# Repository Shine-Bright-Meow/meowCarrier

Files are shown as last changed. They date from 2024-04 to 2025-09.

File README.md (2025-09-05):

# meowCarrier
PCB, case, and accessories as a do-it-yourself solution for SlimeVR Full Body Trackers. Ordering and assembly instructions can be found in the README file.

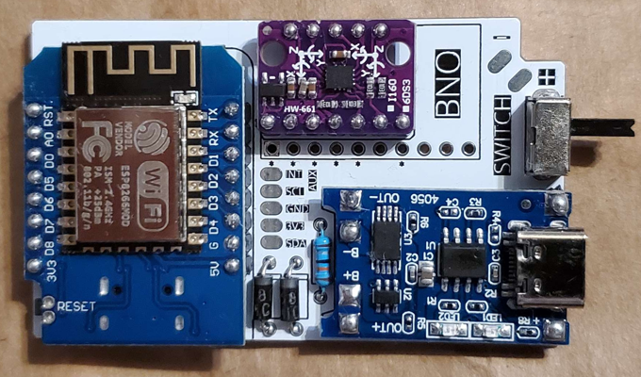
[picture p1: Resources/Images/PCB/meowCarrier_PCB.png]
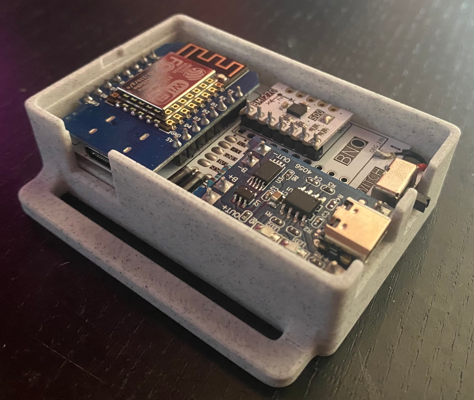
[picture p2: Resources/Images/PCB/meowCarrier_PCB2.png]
<div align="center" valight="center"><br></div>

## Purchasing Guide
### Recommended Components (PCB)
Choose either LSM6DSV / ICM-45686 (Performance) or LSM6DSR (Value) from the list below; not all three.

| Component | Variant | Link |
| --- | --- | --- |
| WeMos D1 Mini | Micro or Type-C (not V4.0.0) | <https://www.aliexpress.us/item/2251832465432818.html><br><https://hz.aliexpress.com/item/3256804158044498.html><br><https://www.aliexpress.us/item/3256805831695231.html> |
| TP4056 | 18650 Micro or Type-C | <https://www.aliexpress.us/item/2251832290307200.html><br><https://www.aliexpress.us/item/2251832397113841.html> |
| ICM-45686 | N/A | <https://shop.slimevr.dev/products/slimevr-mumo-breakout-module-v1-icm-45686-qmc6309> |
| LSM6DSR | N/A | <https://moffshop.deyta.de/products/lsm6dsr> |
| LSM6DSV | N/A | <https://moffshop.deyta.de/products/lsm6dsv-module> |
| SK12D07/SK12D07VG Switch | High 3mm | <https://www.aliexpress.us/item/3256804216279588.html> |
| 1/4W Metal Film Resistor | 180**K** | <https://www.aliexpress.us/item/3256803737288214.html> |
| Schottky Rectifier Diode | 1N5817 | <https://www.aliexpress.us/item/2255800018624086.html> |
| Header Pins | 2.54mm Pitch / Male | <https://www.aliexpress.us/item/3256805804439042.html> |
| Lithium Polymer Ion Battery | 503759 or 523450 without connector | <https://www.aliexpress.us/item/3256805125875396.html><br><https://www.aliexpress.us/item/3256806672906854.html><br><https://www.aliexpress.us/item/3256806672783913.html> |

> [!IMPORTANT]
> Purchase 30% more boards (WeMos D1 Mini and TP4056) than what is needed. There is the possibility that components are dead on arrival or get damaged during assembly or soldering.

> [!NOTE]
> One order of Resistors, Diodes, Header Pins, and Switches is enough for the entire project.

> [!NOTE]
> The SlimeVR DIY Community recommends buying boards from the following sellers on AliExpress: Win Win, Aitexm, or Tenstar Robot.

> [!NOTE]
> Type-C Ports are more durable. As for charging, USB-C to USB-C Power Delivery doesn't work. Use USB-A to USB-C cables to charge trackers.

> [!IMPORTANT]
> When purchasing components, some have multiple variants on the same product page, like Diodes and Resistor. Be sure to select the correct one.

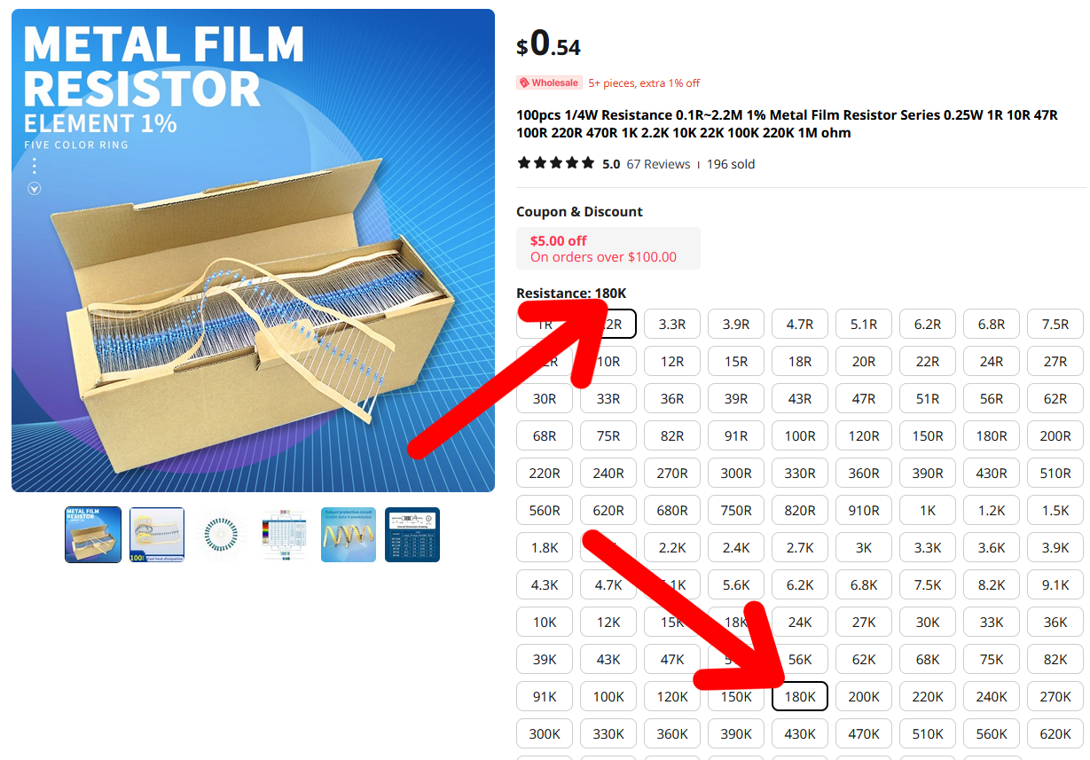
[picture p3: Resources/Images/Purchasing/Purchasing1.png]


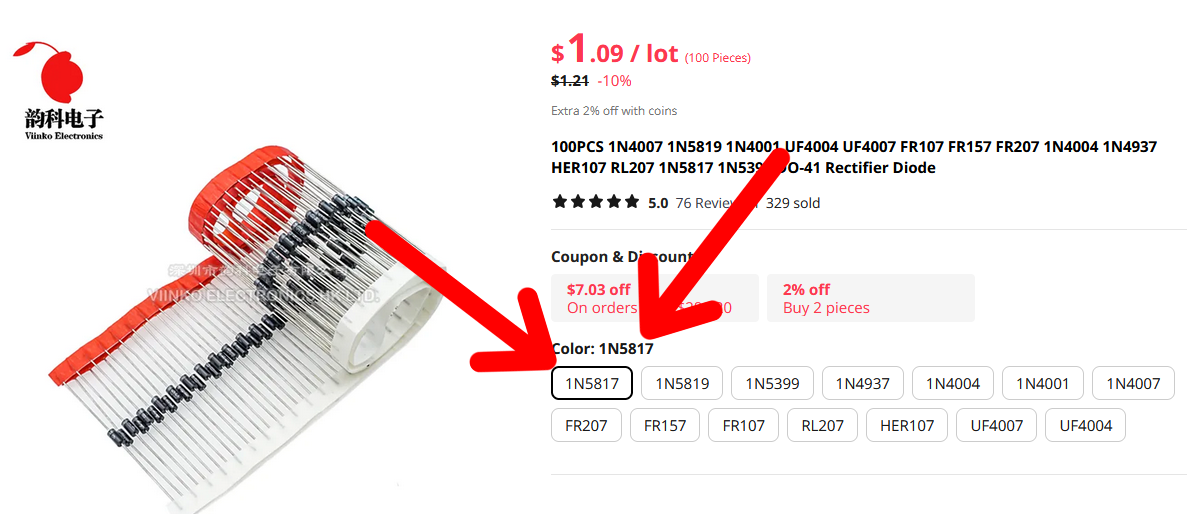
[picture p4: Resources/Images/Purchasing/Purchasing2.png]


> [!TIP]
> In your AliExpress Cart, you can verify that you selected the correct variant of the component here.

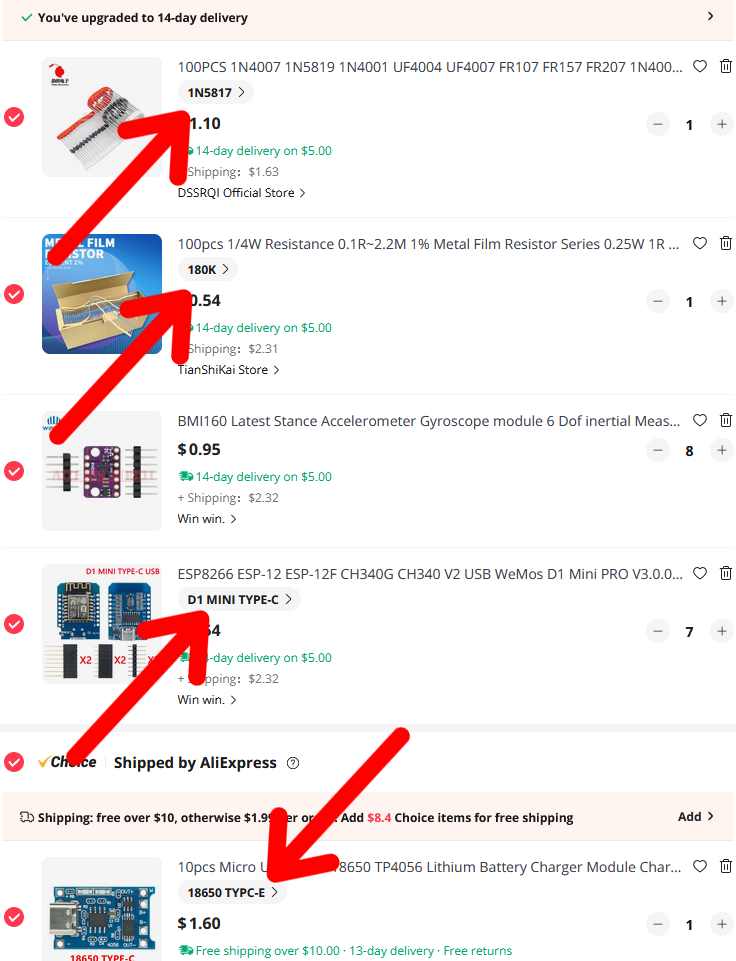
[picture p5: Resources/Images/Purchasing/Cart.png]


### Optional Components (PCB)
| Component | Variant | Link |
| --- | --- | --- |
| Sheathed Wire Cable | 28AWG & 4Cores | <https://www.aliexpress.us/item/2255800384086289.html> |

### Recommended Consumables and Tools
| Component | Variant | Link |
| --- | --- | --- |
| Soldering Iron | Any with BC2 Tip | <https://www.aliexpress.us/item/3256805553022893.html> |
| Solder Sucker| SS-02 or SS-02 Clone | <https://www.aliexpress.us/item/3256805437410900.html> |
| Desoldering Iron| Choose your electrical outlet | <https://www.aliexpress.us/item/3256804929123151.html> |
| Rosin Flux | Liquid or Gel Type | N/A |

> [!NOTE]
> You will have a much better soldering experience with better tools. These are my recommended (but still on a budget) Soldering Iron and Solder Sucker if you don't have these tools or better already. They will work much better than those Amazon $10–20 soldering kits and irons.

> [!NOTE]
> The soldering iron listed requires a USB Type-C Power Delivery charging block of 60W or higher.

### Recommended Components (Case)
| Component | Variant | Link |
| --- | --- | --- |
| Trilancer Elastic Cinch Straps | See note below | <https://www.amazon.com/dp/B099RNRT7Z> |
| GoPro Chest Mount Harness | See note below | <https://www.aliexpress.us/item/3256805774922789.html> |
| GoPro Chest Mount Harness (Chesty) | Option B (with the thumb screw) | <https://www.aliexpress.us/item/2251832640172299.html> |

> [!NOTE]
> 12 inches work for ankles. 18 inches for thinner thighs and 24 inches for thicker thighs. Chest (if not using the GoPro Chest Harness) and Hips can be done by doubling up on 18- or 24-inch straps. Choose what you need for your body and how many trackers you are planning to make. A 3-size combo and either an 18- or 24-inch package would be a start.

> [!NOTE]
> There are two types of GoPro Chest Mount Harness. If the intended user of the trackers has a larger chest, it is recommended to get the "Chesty" harness for comfort. One that clips in, and the other one is fastened by a bolt. Be sure to print the correct GoPro Adapter case.

### Ordering PCBs from JLCPCB
1. Download the Gerber file from [here](https://github.com/Shine-Bright-Meow/meowCarrier/raw/main/PCB/PCB_meowCarrier.zip).
2. Go to [JLCPCB](https://jlcpcb.com).
3. Click on "Add Gerber File" and upload the zip Gerber file.

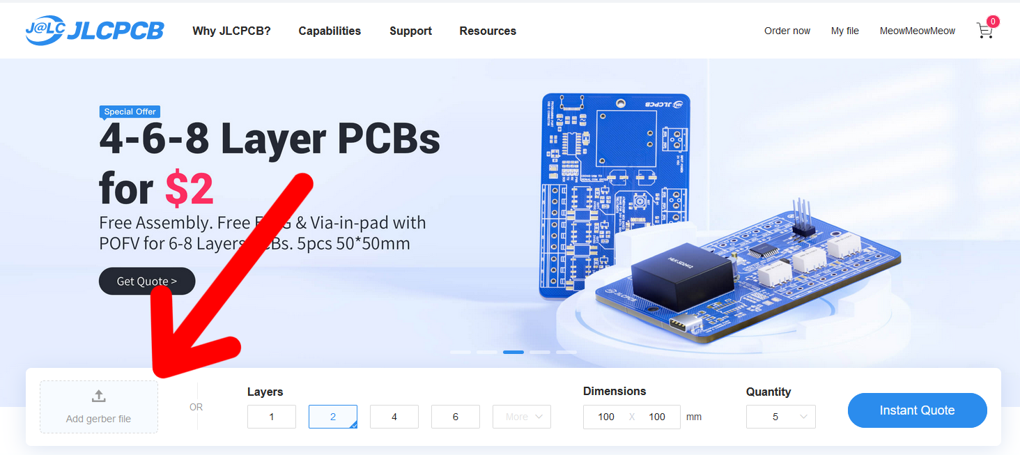
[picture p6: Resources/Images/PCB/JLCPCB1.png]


4. Select the PCB Qty and PCB Color of your choice. Select 0.8mm (recommended) or 1.0mm for PCB Thickness and select "Specify a location" for Remove Order Number.

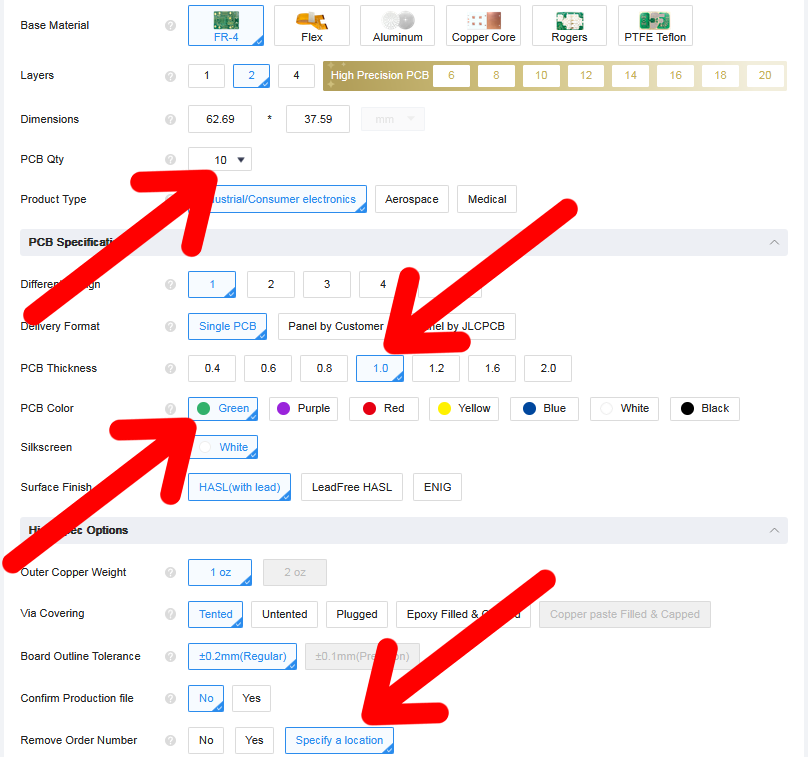
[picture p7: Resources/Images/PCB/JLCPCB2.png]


> [!NOTE]
> Using 0.8mm will give you more assembly tolerance and the tracker will be slightly lighter.

> [!NOTE]
> JLCPCB usually manufactures Green colored PCB the quickest. Other colors have additional days added.

> [!NOTE]
> For Remove Order Number, when "Specify a Location" is selected, JLCPCB will print the order number at where the text **JLCJLCJLCJLC** is located. In this case, at the bottom of the TP4056 module footprint.
5. Click to View Cart.

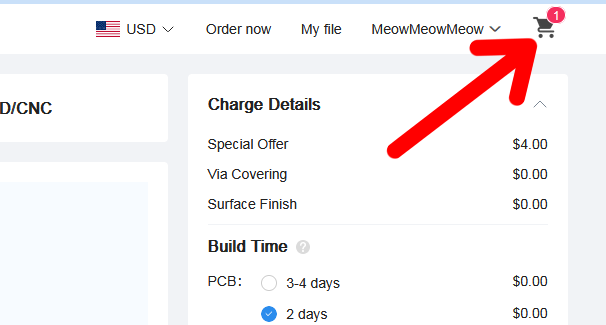
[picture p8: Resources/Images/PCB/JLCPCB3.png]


6. Click Secure Checkout.

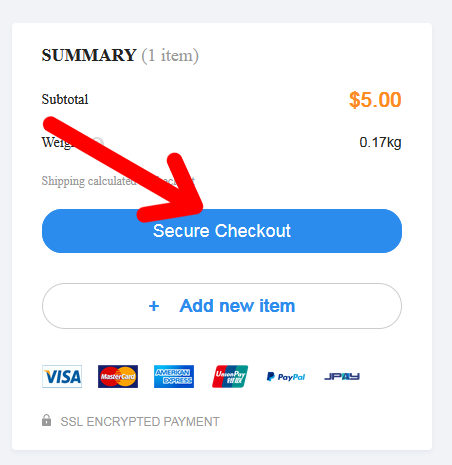
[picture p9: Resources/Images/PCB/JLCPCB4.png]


7. In the Shipping section, there are cheaper options not chosen by default.

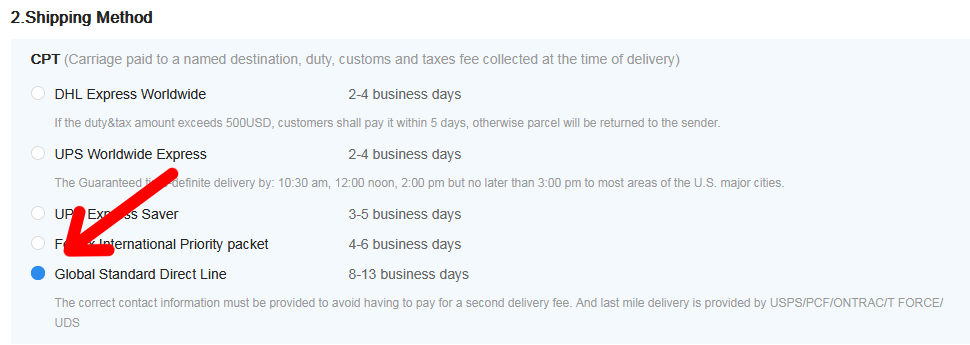
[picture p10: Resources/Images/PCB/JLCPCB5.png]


## Soldering/Assembly Guide

### Written Guide

> [!WARNING]
> Please work in a well-ventilated area. It is recommended to use a fume extractor if working indoors. If you do not have one, use a fan to blow fumes or smoke away from your face.

> [!WARNING]
> It is recommended to use eye production. Especially when splitting header pins apart with a cutter and when trimming down header pins and ends of resistors and diodes.

> [!WARNING]
> If working with leaded solder, be sure to wash your hands when you are done, including under your fingernails. Wipe down and vacuum the floors and surfaces of your workspace and anything you may have cross-contaminated.

> [!TIP]
> Using external flux (preferably Rosin) will allow the solder to flow automatically flow into the correct area.

> [!TIP]
> A wooden clothespin can be used to hold the boards together while soldering.

##### Diodes

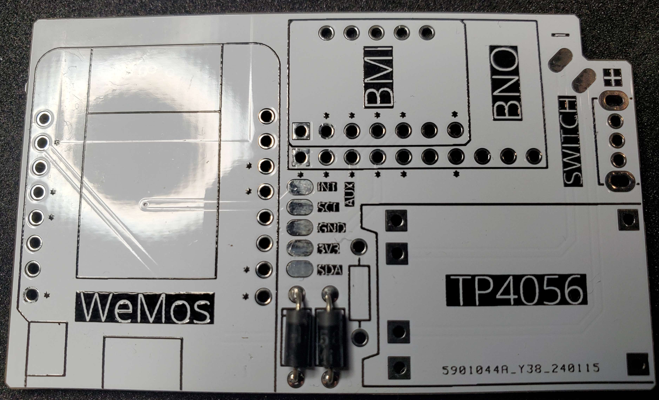
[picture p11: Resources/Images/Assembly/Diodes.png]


> [!NOTE]
> Make sure the diode is facing the correct direction and has the correct values.

1. Verify that the diodes are 1N5817. You can find the text in the body.

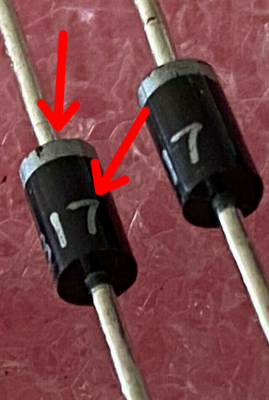
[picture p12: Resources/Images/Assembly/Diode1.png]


2. Place the diode's striped (grey or silver) on the narrow stripe indicated on the silkscreen.

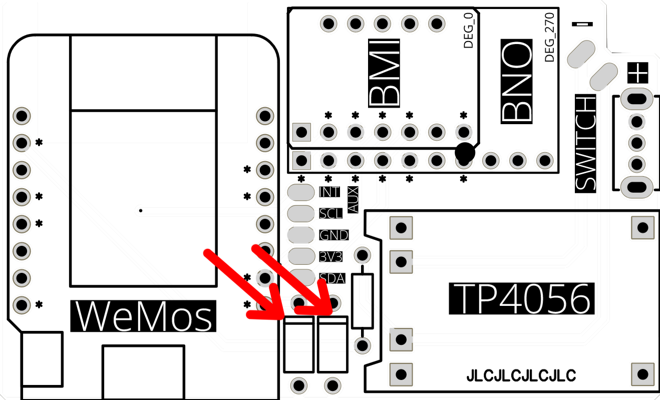
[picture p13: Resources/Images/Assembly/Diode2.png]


3. Bend the ends in 90 degrees so they are shaped like a staple and place them into the through-hole.
4. Pull the excess on the back until the diode is flush with the PCB.
5. Solder ends from the back.
6. Repeat for the other diode.
7. Trim the excess length of the pins using a flush cutter. Use your wire cutter if you don't have a flush cutter, and cut as close to the PCB as you can.

##### Resistor

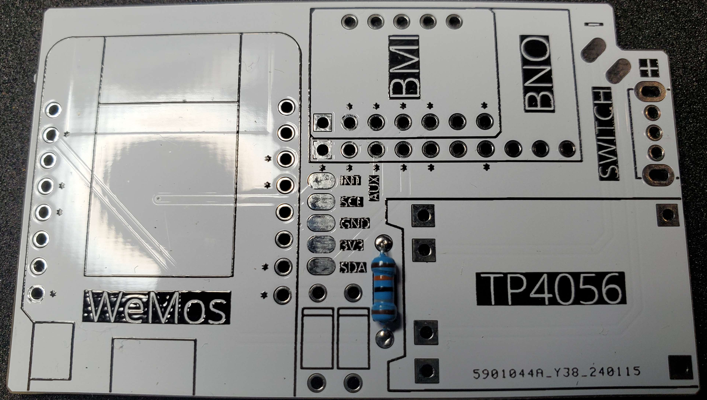
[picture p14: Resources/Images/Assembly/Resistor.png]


> [!NOTE]
> Make sure the resistor has the correct value.

1. Verify the resistor is 180K. The first four colors should go in this order:
- Brown
- Grey
- Black
- Orange

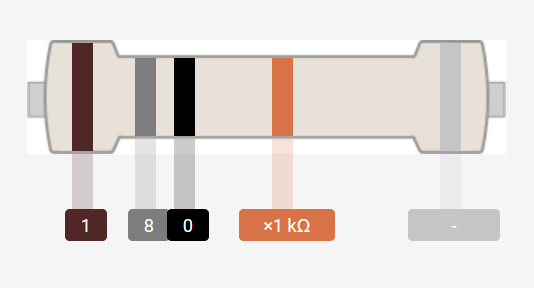
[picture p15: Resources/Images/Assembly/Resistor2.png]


2. Bend the ends in 90 degrees so they are shaped like a staple and place them into the through-hole. Resistors are not polarized, so the direction does not matter.
3. Pull the excess on the back until the resistor is flush with the PCB.
4. Trim the excess length of the pins using a flush cutter. Use your wire cutter if you don't have a flush cutter, and cut as close to the PCB as you can.

> [!NOTE]
> Unlike Diodes, Resistors can go into the PCB in any direction.

#### Charging Board (TP4056)

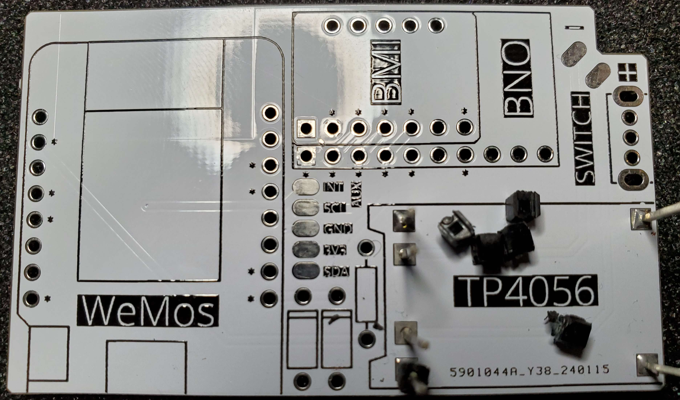
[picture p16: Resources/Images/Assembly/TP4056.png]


1. Break the header into individual pins.
2. Place individual pins into the through-holes.
3. Place the TP4056 on top of the header pins to sandwich them in place.
4. If needed, use a clamp, like a wooden clothespin, to hold everything in place.
5. Solder the pins to the back of the PCB.
6. Remove the TP4056 from the PCB and header pins.
7. Using a plier, carefully remove the black plastic spacer from the header pins.
8. Replace the TP4056 back through the Header pins.
9. Solder the header pins and top side of the TP4056.
10. Trim the excess length of pins using a flush cutter on the back side of the PCB and the top side of the TP4056. Use your wire cutter if you don't have a flush cutter, and cut as close to the PCB as you can.

#### IMU (ICM-45686, LSM6DSR, or LSM6DSV)

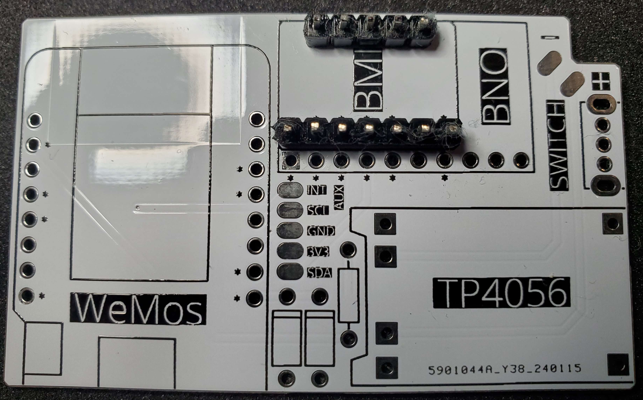
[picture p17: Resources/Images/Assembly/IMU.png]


1. Break a row of header pins with the same amount of through-holes as the IMU breakout board.
2. Place the header pins in the corresponding through-holes of the PCB.
3. Solder the pins to the back of the PCB.
4. Solder the header pins and top side of the IMU.
5. Trim the excess length of pins using a flush cutter on the back side of the PCB and the top side of the IMU. Use your wire cutter if you don't have a flush cutter, and cut as close to the PCB as you can.

#### MCU (WeMos D1 Mini)

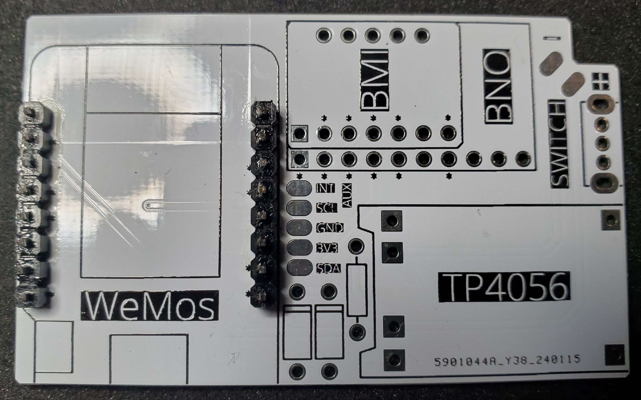
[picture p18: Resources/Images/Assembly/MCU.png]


1. Flash the D1 Mini with WiFi credentials to ensure the board is in working condition first.
2. Place both rows of header pins into the through-holes of the PCB.
3. Place D1 Mini on top of the header pins to sandwich them in place.
4. If needed, use a clamp, like a wooden clothespin, to hold everything in place.
5. Solder the pins to the back of the PCB.
6. Solder the header pins and top side of the D1 Mini.
7. Trim the excess length of pins using a flush cutter on the back side of the PCB and top side of the D1 Mini. Use your wire cutter if you don't have a flush cutter, and cut as close to the PCB as you can.

#### Switch

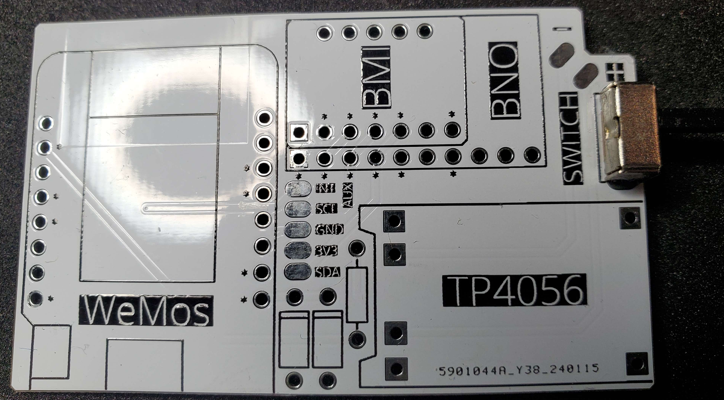
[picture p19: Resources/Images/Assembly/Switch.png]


1. Place the Switch into the through-holes of the PCB.
2. Solder the 3 pins and the 2 supports on the back of the PCB.
3. Trim the excess length of pins and supports using a flush cutter on the back side of the PCB.

#### Extension Cable/Wire

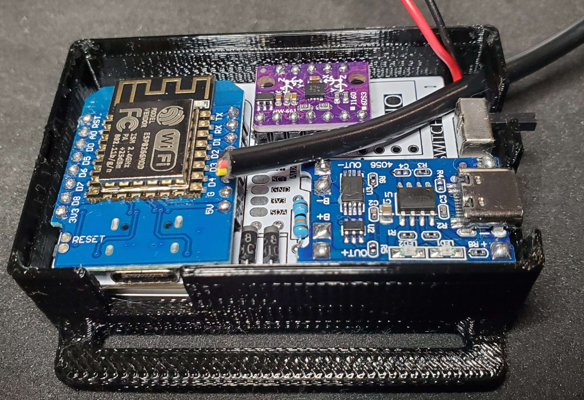
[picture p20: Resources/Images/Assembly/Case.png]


1. Put the cable or wire through the hole on your main or AUX case.
2. Take your PCB outside of the case with the wires.
3. If using a cable, cut the jacket to expose the wires inside.
4. Strip the wires to the length of the solder pads for the extensions.
5. Tin the pads by heating them up and applying solder.
6. Place the exposed copper area of the wire on the tin pads and reheat.
7. Match 3V3, GND, SDA, and SCL wire colors on your Main and AUX trackers.
8. Verify both trackers are working before hotgluing the outside hole of the case to ensure the cable or wire doesn't get pulled out. (This is the last step after the complete tracker is assembled.).

> [!IMPORTANT]
> Do not solder anything inside the main or AUX case! Pull the extension cable or wire outside of the case with the board before soldering.

#### Battery

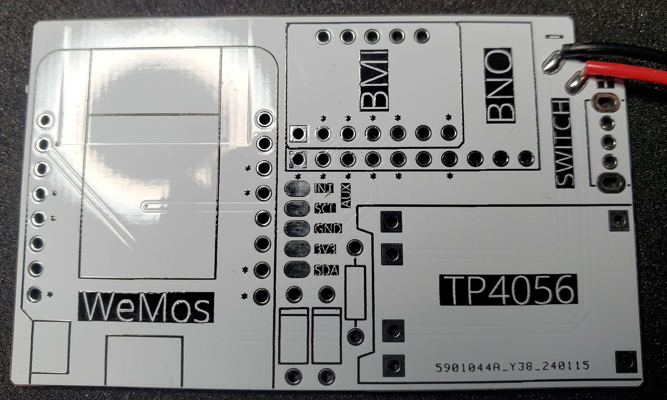
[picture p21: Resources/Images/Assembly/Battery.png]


1. Strip the wires to the length of the solder pads for the battery.
2. Tin the pads by heating them up and applying solder.
3. Place the exposed copper area of the wire on the tin pads and reheat.
4. Match the Red wire with the + side and the Black wire with the - side.

> [!WARNING]
> Do not let the exposed battery leads make contact with each other.

> [!IMPORTANT]
> To prevent shorting the PCB or other components, this is the last step in completing the assembly of your tracker. (Right before hotgluing the extension cable or wire to the outside hole of the cases.)

## 3D Printable Case and Accessories Guide
The main case consists of 3 files: Case, Lid, and Tray.

Printer Settings used:
- **Printer:** Creality CR-10 S5
- **Infill:** 100%
- **No** Rafts or Supports
- **Resolution:** 0.2mm
- **Nozzle:** 0.4mm
- Tested with PLA+ and PETG

> [!TIP]
> For stronger strap loops, print the base/bottom 4mm layers with 0% (solid) infill for just the **case** file. Printing with a zig-zap pattern instead of a line will help prevent strap loops from breaking at the weak point where layers join horizontally or vertically. These are done in your Slicer.

### Case

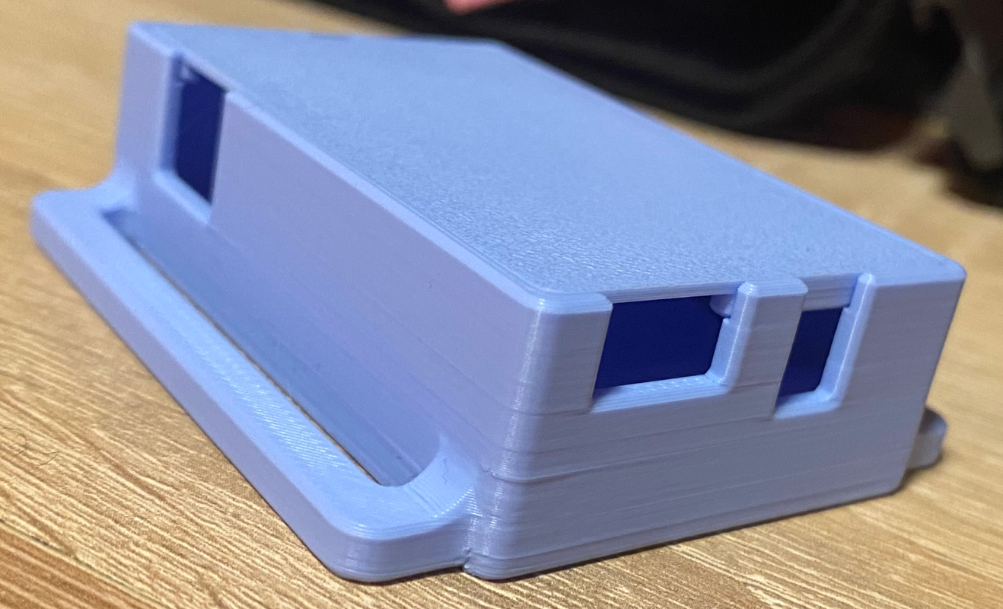
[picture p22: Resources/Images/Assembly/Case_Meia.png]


Case photo by Meia (Higanbana)

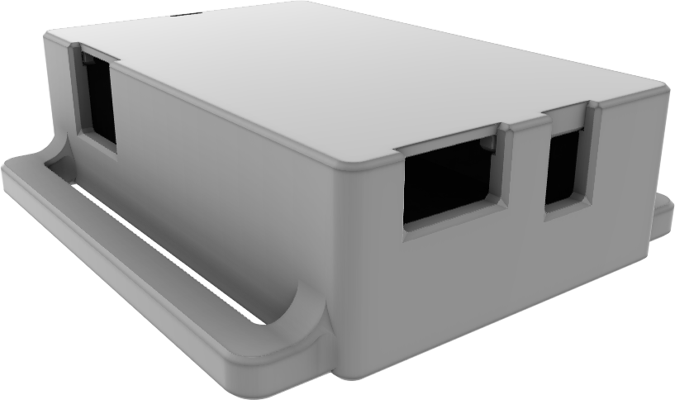
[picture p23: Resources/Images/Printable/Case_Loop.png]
Case with Strap Loops
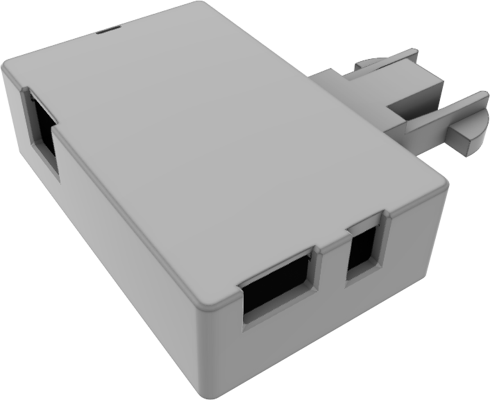
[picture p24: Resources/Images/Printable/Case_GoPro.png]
Case with GoPro Adapter Buckle
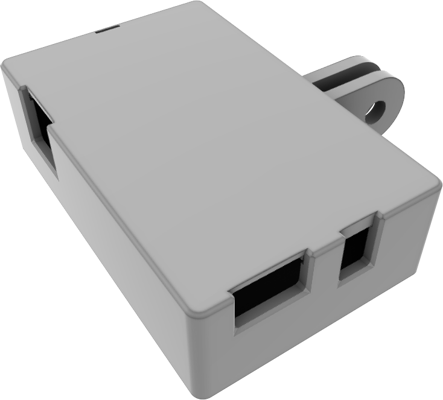
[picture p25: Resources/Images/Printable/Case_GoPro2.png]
Case with GoPro Adapter Swivel
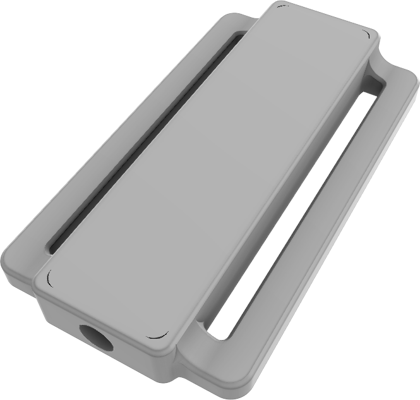
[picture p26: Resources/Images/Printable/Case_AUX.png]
AUX Case


| Battery | Case Type | Variant | AUX Cutout | STL | STEP |
| --- | --- | --- | --- | --- | --- |
| 503759 | Main | 50mm Strap | No | [CASE_meowCarrier_503759_Straps.stl](https://github.com/Shine-Bright-Meow/meowCarrier/raw/main/Printables/STL/CASE_meowCarrier_503759_Straps.stl) | [CASE_meowCarrier_503759_Straps.step](https://github.com/Shine-Bright-Meow/meowCarrier/raw/main/Printables/STEP/CASE_meowCarrier_503759_Straps.step) |
| 503759 | Main | 50mm Strap | Yes | [CASE_meowCarrier_503759_Straps_AUX.stl](https://github.com/Shine-Bright-Meow/meowCarrier/raw/main/Printables/STL/CASE_meowCarrier_503759_Straps_AUX.stl) | [CASE_meowCarrier_503759_Straps_AUX.step](https://github.com/Shine-Bright-Meow/meowCarrier/raw/main/Printables/STEP/CASE_meowCarrier_503759_Straps_AUX.step) |
| 503759 | Main | GoPro Adapter1 | No | [CASE_meowCarrier_503759_GoPro.stl](https://github.com/Shine-Bright-Meow/meowCarrier/raw/main/Printables/STL/CASE_meowCarrier_503759_GoPro.stl) | [CASE_meowCarrier_503759_GoPro.step](https://github.com/Shine-Bright-Meow/meowCarrier/raw/main/Printables/STEP/CASE_meowCarrier_503759_GoPro.step) |
| 503759 | Main | GoPro Adapter1 | Yes | [CASE_meowCarrier_503759_GoPro_AUX.stl](https://github.com/Shine-Bright-Meow/meowCarrier/raw/main/Printables/STL/CASE_meowCarrier_503759_GoPro_AUX.stl) | [CASE_meowCarrier_503759_GoPro_AUX.step](https://github.com/Shine-Bright-Meow/meowCarrier/raw/main/Printables/STEP/CASE_meowCarrier_503759_GoPro_AUX.step) |
| 503759 | Main | GoPro Adapter2 | No | [CASE_meowCarrier_503759_GoPro2.stl](https://github.com/Shine-Bright-Meow/meowCarrier/raw/main/Printables/STL/CASE_meowCarrier_503759_GoPro2.stl) | [CASE_meowCarrier_503759_GoPro2.step](https://github.com/Shine-Bright-Meow/meowCarrier/raw/main/Printables/STEP/CASE_meowCarrier_503759_GoPro2.step) |
| 503759 | Main | GoPro Adapter2 | Yes | [CASE_meowCarrier_503759_GoPro2_AUX.stl](https://github.com/Shine-Bright-Meow/meowCarrier/raw/main/Printables/STL/CASE_meowCarrier_503759_GoPro2_AUX.stl) | [CASE_meowCarrier_503759_GoPro2_AUX.step](https://github.com/Shine-Bright-Meow/meowCarrier/raw/main/Printables/STEP/CASE_meowCarrier_503759_GoPro2_AUX.step) |
| N/A | AUX | BMI Breakout Board | Yes | [CASE_meowCarrier_AUX_BMI.stl](https://github.com/Shine-Bright-Meow/meowCarrier/raw/main/Printables/STL/CASE_meowCarrier_AUX_BMI.stl) | [CASE_meowCarrier_AUX_BMI.step](https://github.com/Shine-Bright-Meow/meowCarrier/raw/main/Printables/STEP/CASE_meowCarrier_AUX_BMI.step) |
| N/A | AUX | BNO Breakout Board | Yes | [CASE_meowCarrier_AUX_BNO.stl](https://github.com/Shine-Bright-Meow/meowCarrier/raw/main/Printables/STL/CASE_meowCarrier_AUX_BNO.stl) | [CASE_meowCarrier_AUX_BNO.step](https://github.com/Shine-Bright-Meow/meowCarrier/raw/main/Printables/STEP/CASE_meowCarrier_AUX_BNO.step) |

> [!IMPORTANT]
> Print the Main Case with GoPro Adapter1 for the normal GoPro Chest Harness (Buckle).

> [!IMPORTANT]
> Print Main Case with GoPro Adapter2 for the "Chesty" GoPro Chest Harness or for the GoPro Headstrap (vTubing and Motion Capture).

> [!IMPORTANT]
> GoPro Chest Harness Tracker will have a different IMU rotation than your other trackers.

### Lid
  
| Battery | Case Type | STL | STEP |
| --- | --- | --- | --- |
| 503759 | Main | [LID_meowCarrier_503759.stl](https://github.com/Shine-Bright-Meow/meowCarrier/raw/main/Printables/STL/LID_meowCarrier_503759.stl) | [LID_meowCarrier_503759.step](https://github.com/Shine-Bright-Meow/meowCarrier/raw/main/Printables/STEP/LID_meowCarrier_503759.step) |
| N/A | AUX | [LID_meowCarrier_AUX.stl](https://github.com/Shine-Bright-Meow/meowCarrier/raw/main/Printables/STL/LID_meowCarrier_AUX.stl) | [LID_meowCarrier_AUX.step](https://github.com/Shine-Bright-Meow/meowCarrier/raw/main/Printables/STEP/LID_meowCarrier_AUX.step) |

### Tray
  
| Battery | Case Type | STL | STEP |
| --- | --- | --- | --- |
| 503759 | Main | [TRAY_meowCarrier_503759.stl](https://github.com/Shine-Bright-Meow/meowCarrier/raw/main/Printables/STL/TRAY_meowCarrier_503759.stl) | [TRAY_meowCarrier_503759.step](https://github.com/Shine-Bright-Meow/meowCarrier/raw/main/Printables/STEP/TRAY_meowCarrier_503759.step) |

### Accessories

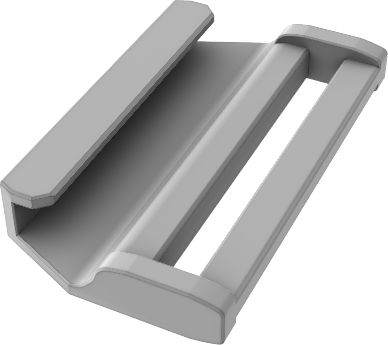
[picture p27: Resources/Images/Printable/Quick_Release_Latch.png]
Quick Release Latch for Straps

 
| Item Name | Variant | STL | STEP |
| --- | --- | --- | --- |
| Quick Release Latch | 25mm Straps | [Quick_Release_Latch_25mm.stl](https://github.com/Shine-Bright-Meow/meowCarrier/raw/main/Printables/STL/Quick_Release_Latch_25mm.stl) | [Quick_Release_Latch_25mm.step](https://github.com/Shine-Bright-Meow/meowCarrier/raw/main/Printables/STEP/Quick_Release_Latch_25mm.step) |
| Quick Release Latch | 38-40mm Straps | [Quick_Release_Latch_38mm.stl](https://github.com/Shine-Bright-Meow/meowCarrier/raw/main/Printables/STL/Quick_Release_Latch_38mm.stl) | [Quick_Release_Latch_38mm.step](https://github.com/Shine-Bright-Meow/meowCarrier/raw/main/Printables/STEP/Quick_Release_Latch_38mm.step) |
| Quick Release Latch | 50mm Straps | [Quick_Release_Latch_50mm.stl](https://github.com/Shine-Bright-Meow/meowCarrier/raw/main/Printables/STL/Quick_Release_Latch_50mm.stl) | [Quick_Release_Latch_50mm.step](https://github.com/Shine-Bright-Meow/meowCarrier/raw/main/Printables/STEP/Quick_Release_Latch_50mm.step) |

## Troubleshooting
Join the [SlimeVR Discord](https://discord.gg/SlimeVR) and ask in either the #technical-support or #DIY channels. It would be helpful for you to provide a description of your issue, photos of your soldering (front and back), and a log output from Settings > Serial Console with your tracker plugged into your computer via a data USB cable into your WeMos D1 Port (non-charging). You will need to press the **Reboot** button to get the complete log.

## Contribute
Feel free to create a pull request to this repository or mention me in SlimeVR's Discord #DIY channel (do not DM me; it will go to my Message Request and I will not reply to you there) for improvement ideas or your modifications of the source files below or to the guide above.

### Source Files
| Component | Link |
| --- | --- |
| Case and Quick Release Latch | Fusion 360 Files - [meowCarrier.f3d](https://github.com/Shine-Bright-Meow/meowCarrier/raw/main/Printables/Fusion360/meowCarrier.f3d) |
| PCB | <https://oshwlab.com/newbie2620/meowcarrier> |

## Credit
| Contributor | Description | Link |
| --- | --- | --- |
| Shine Bright | PCB and Case Design, Quick Release Latch for Straps, and this guide write-up in this repository | <https://github.com/Shine-Bright-Meow/meowCarrier> |
| Meia | Marble Blue Case Photo | <https://github.com/kounocom> |

## Licence
This project is licensed under the MIT license.

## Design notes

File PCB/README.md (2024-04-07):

This directory contains the Gerber and Schematic files to the PCB.

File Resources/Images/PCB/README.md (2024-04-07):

This directory contains images for the ordering PCB section of the documentation.

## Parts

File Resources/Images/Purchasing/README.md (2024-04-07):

This directory contains images for the puchasing section of the documentation.

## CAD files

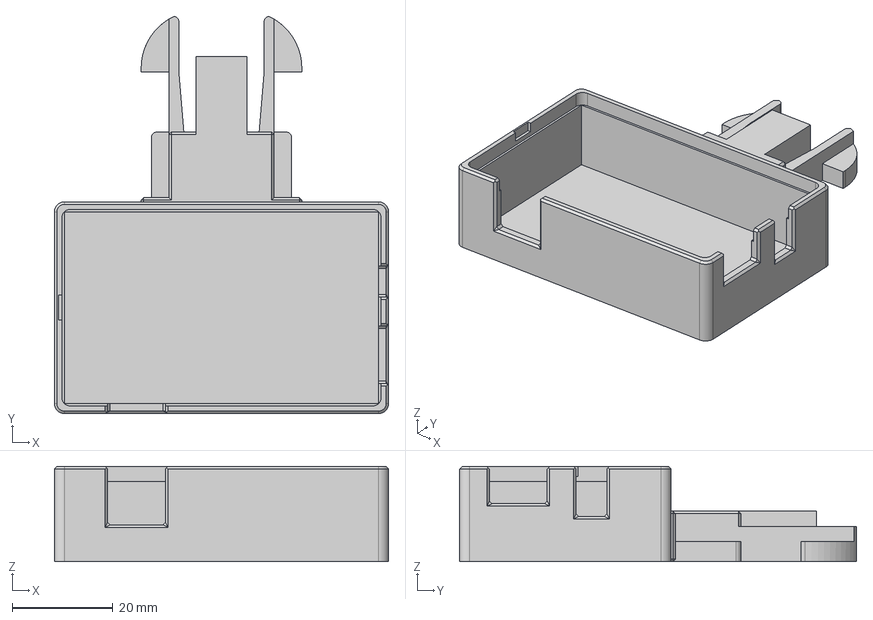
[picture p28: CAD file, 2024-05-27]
Printables/STEP/CASE_meowCarrier_503759_GoPro.step
66.5 x 79.0 x 18.9 mm
GoPro_Adapter2 v2
Adapter

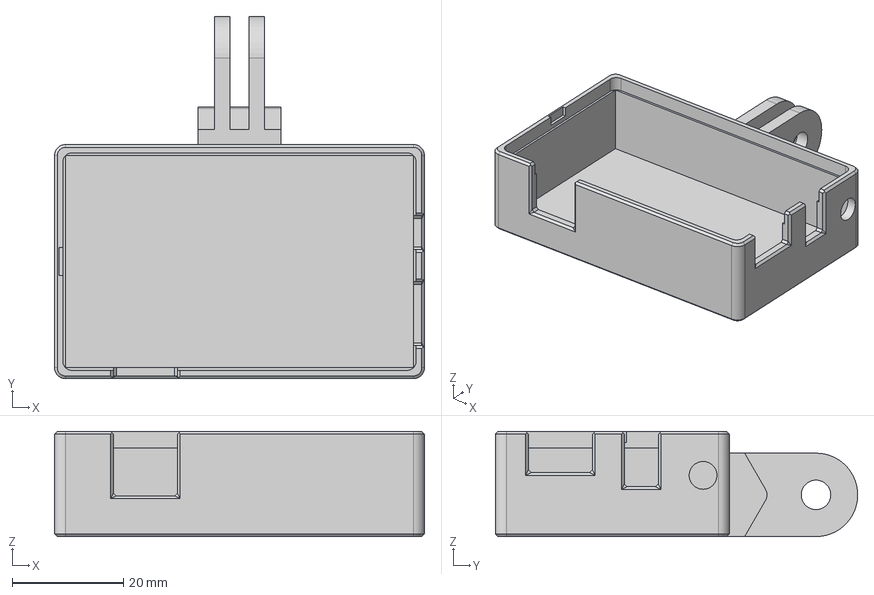
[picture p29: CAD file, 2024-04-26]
Printables/STEP/CASE_meowCarrier_503759_GoPro2_AUX.step
66.5 x 65.1 x 18.9 mm

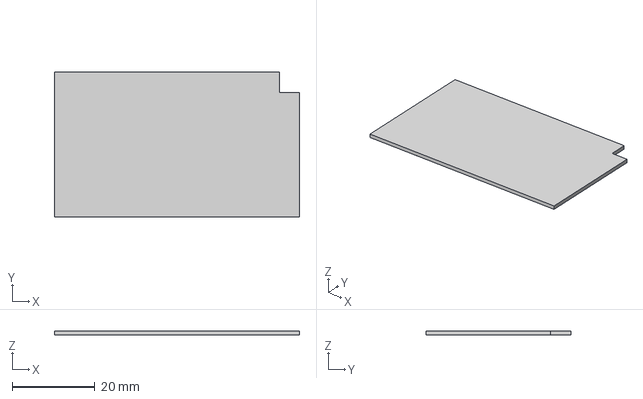
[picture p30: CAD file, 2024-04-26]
Printables/STEP/TRAY_meowCarrier_503759.step
59.3 x 35.1 x 1.00 mm

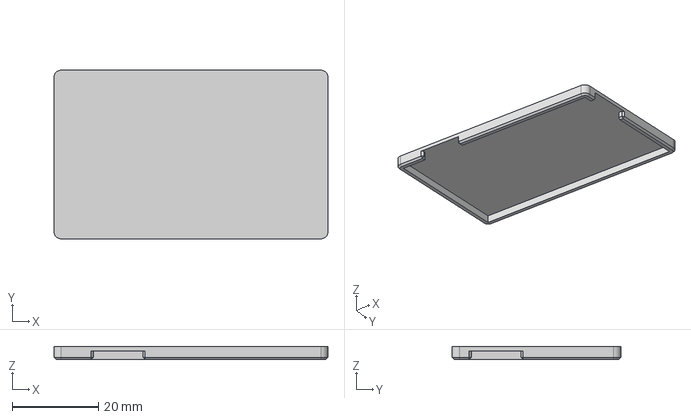
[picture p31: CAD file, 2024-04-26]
Printables/STEP/LID_meowCarrier_503759.step
63.5 x 39.1 x 3.00 mm

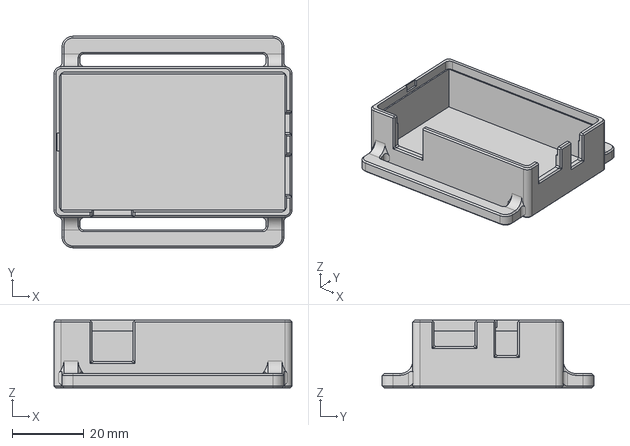
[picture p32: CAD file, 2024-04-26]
Printables/STEP/CASE_meowCarrier_503759_Straps.step
66.5 x 59.1 x 18.9 mm

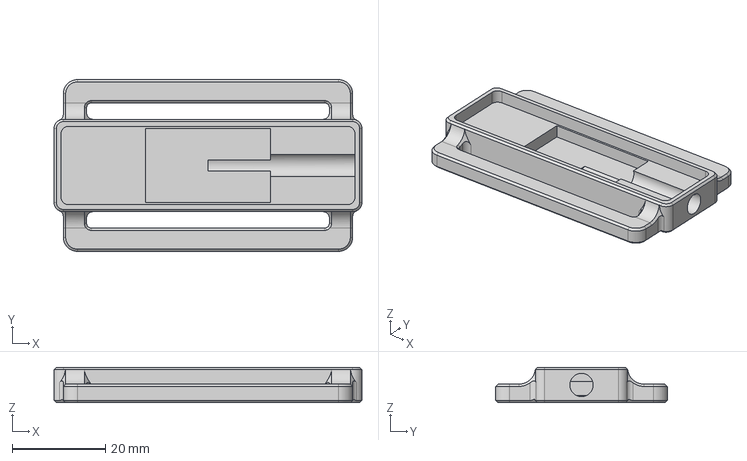
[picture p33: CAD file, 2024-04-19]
Printables/STEP/CASE_meowCarrier_AUX_BNO.step
66.0 x 36.8 x 7.60 mm

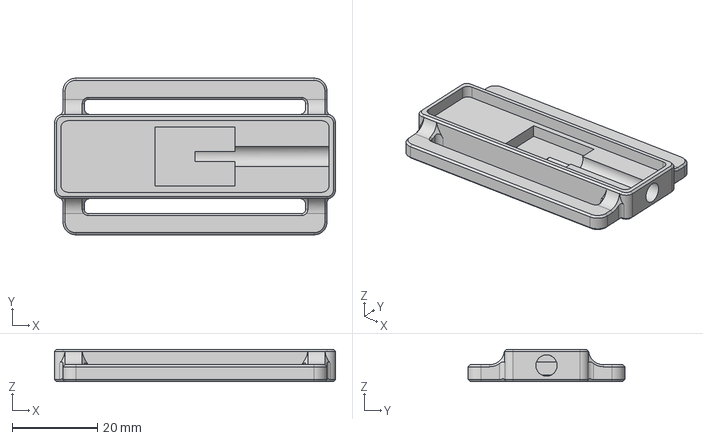
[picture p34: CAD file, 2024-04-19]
Printables/STEP/CASE_meowCarrier_AUX_BMI.step
66.0 x 36.8 x 7.60 mm

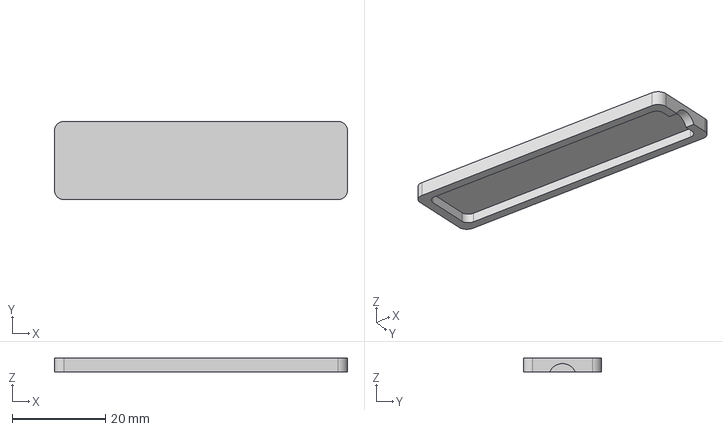
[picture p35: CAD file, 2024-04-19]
Printables/STEP/LID_meowCarrier_AUX.step
63.0 x 16.8 x 3.00 mm

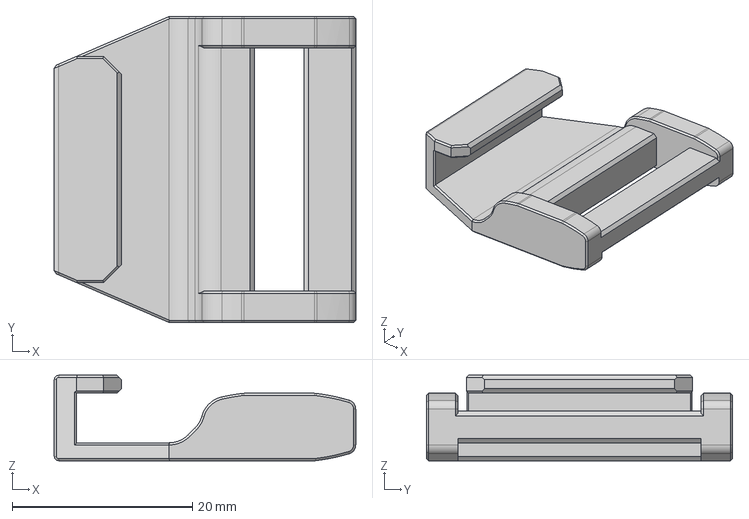
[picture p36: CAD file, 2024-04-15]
Printables/STEP/Quick_Release_Latch_25mm.step
33.5 x 34.0 x 9.50 mm

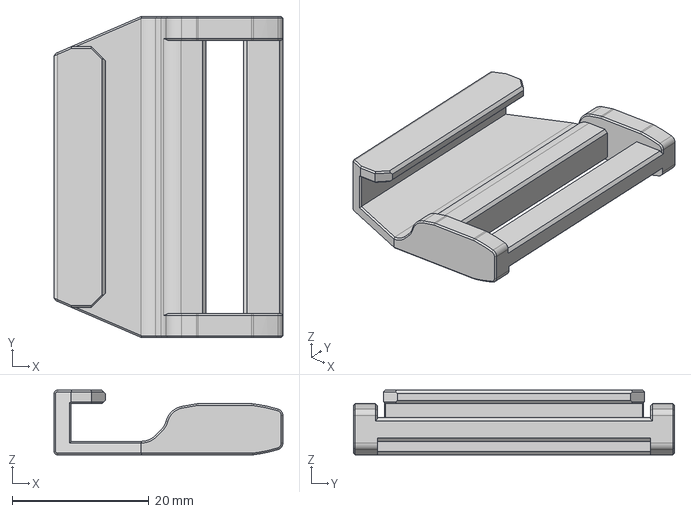
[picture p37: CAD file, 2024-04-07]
Printables/STEP/Quick_Release_Latch_38mm.step
33.5 x 47.0 x 9.50 mm

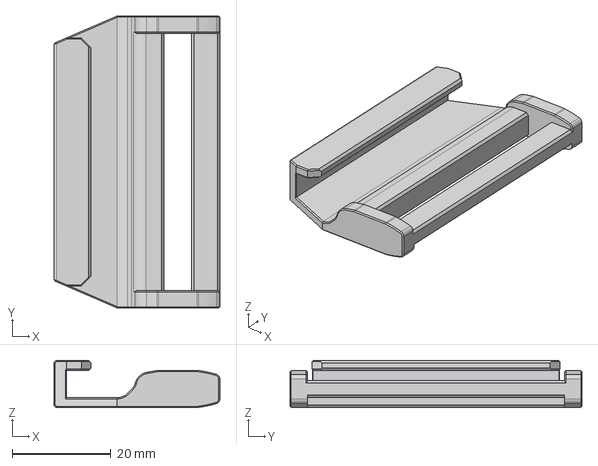
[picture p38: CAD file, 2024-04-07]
Printables/STEP/Quick_Release_Latch_50mm.step
33.5 x 59.0 x 9.50 mm

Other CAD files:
Printables/STEP/CASE_meowCarrier_503759_GoPro_AUX.step
Printables/STEP/CASE_meowCarrier_503759_GoPro2.step
Printables/STEP/CASE_meowCarrier_503759_Straps_AUX.step
Printables/STL/CASE_meowCarrier_503759_GoPro.stl
Printables/STL/CASE_meowCarrier_503759_GoPro2.stl
Printables/STL/CASE_meowCarrier_503759_GoPro2_AUX.stl
Printables/STL/CASE_meowCarrier_503759_GoPro_AUX.stl
Printables/STL/CASE_meowCarrier_503759_Straps.stl
Printables/STL/CASE_meowCarrier_503759_Straps_AUX.stl
Printables/STL/CASE_meowCarrier_AUX_BMI.stl
Printables/STL/CASE_meowCarrier_AUX_BNO.stl
Printables/STL/LID_meowCarrier_503759.stl
Printables/STL/LID_meowCarrier_AUX.stl
Printables/STL/Quick_Release_Latch_25mm.stl
Printables/STL/Quick_Release_Latch_38mm.stl
Printables/STL/Quick_Release_Latch_50mm.stl
Printables/STL/TRAY_meowCarrier_503759.stl

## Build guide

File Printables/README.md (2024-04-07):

This directory contains STL and CAD Models to the 3D Printable Case and Accessories.

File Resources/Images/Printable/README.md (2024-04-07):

This directory contains images for the 3D Printable selection of the documentation.

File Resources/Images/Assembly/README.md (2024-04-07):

This directory contains images for the Assembly section of the documentation.

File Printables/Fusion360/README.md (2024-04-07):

This directory contains Fusion 360 files.

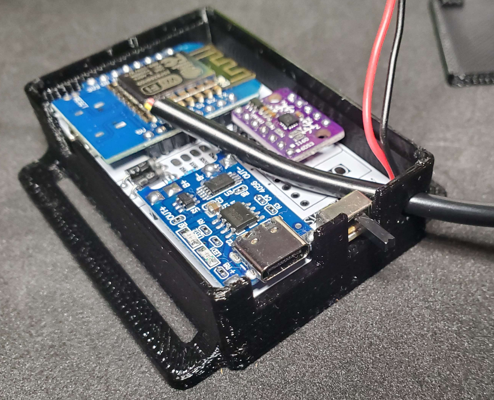
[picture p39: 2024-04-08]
Resources/Images/Assembly/Extension.png

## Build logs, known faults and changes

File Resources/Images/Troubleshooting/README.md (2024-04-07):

This directory contains images for the troubleshooting section of the documentation.

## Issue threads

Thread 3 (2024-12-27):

Back of the PCB has a lot of stuff on it.

christmaswreath, 2024-12-27:
I understand wanting to attach info and a watermark, but seriously there's a LOT on the back of the case. Maybe make a variant without the Discord info and with a smaller watermark on there. I tried editing it again, since I modified the silkscreen when I ordered them but since I'm not good at designing PCBs (It's my first time) I ended up with this.
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
It's not aligned properly, and half of the text is the wrong way but you can still see what I was thinking of. Maybe have one without or with a smaller watermark that you can't use commercially. It would be easier if the KiCad (or other software) files were in the repo.

ShineBrightMeow, 2024-12-27:
I will take a look at it. Which PCB service are you using? The silkscreen looked fine for JLCPCB and PCBWay. My newer PCBs are made with KiCAD. I have been working on a newer revision of this board for flush mounted components, so the case will be about 6-8mm shorter than the current one, but it is an edit of the original PCB on EasyEDA.
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

christmaswreath, 2024-12-27:
It's not an issue with your silkscreen, I think I accidentally moved mine.

christmaswreath, 2024-12-27:
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
Could be something like this instead

christmaswreath, 2024-12-27:
Oh yea, feel free to steal my design, I don't need credit but it would be nice to have in the README :)

christmaswreath, 2025-01-18:
bumping this

ShineBrightMeow, 2025-01-18:
It is still being worked on. Very limited on time during the weekend and no free time on weekdays. Slowly recreating some of the SVG files.

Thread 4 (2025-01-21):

A smaller AUX tracker case

christmaswreath, 2025-01-21:
I know the current tracker case is meant to fit the straps that go along with the other trackers but it would be much nicer to have the AUX trackers be smaller as I don't want such a big tracker on my foot. Maybe they could be 1.5 inches long. I don't know how to use Fusion 360 so it would be appreciated if you could make them smaller :)

ShineBrightMeow, 2025-01-23:
It may be doable with 25mm or 30mm straps, but the height will need to remain the same for the cable. Unless you use some type of flatter wires and the case can also be shorter, but then strain relief may be an issue.

christmaswreath, 2025-01-23:
I just meant making it not as long, there's a huge space of nothing that could definitely be removed.

ShineBrightMeow, 2025-01-24:
It wouldn't be long enough for 50mm (2in) straps. That is why I am asking if you will be using 25-30mm straps instead of the case was that short?

christmaswreath, 2025-01-24:
That was what I was thinking about. Trilancer has 1.5 inch bands but I'll bet I could find some other ones that are 1 inch.

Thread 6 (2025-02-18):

TP4056 doesn't trigger USB-C PD chargers

Theray070696, 2025-02-18:
Hihi,
Just got a set of these put together, and noticed they don't charge when using C-to-C cables from a USB-PD source. They charge fine when going from a USB-A source to the USB-C port, which makes it look like the TP4056 board doesn't have the needed resistors to the CC lines to trigger USB-PD sources. Might be worthwhile to switch to a board that does trigger USB-PD at 5v, or having a guide on how to hotwire the TP4056 to trigger PD.

Source for triggering USB-PD: https://forum.digikey.com/t/simple-way-to-use-usb-type-c-to-get-5v-at-up-to-3a-15w/7016

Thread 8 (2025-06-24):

Wemos D1 mini disables after soldering?

DJ-SX, 2025-06-24:
First of all, Thank you for reading this.

Hello, I have some questions to ask!

So I managed to make trackers to use them in VRChat.
But, after complete soldering, some Wemos become soft-bricked.

[In detail - after soldering]
Switch-On : No LED, can't tell if it's on or off. (can be charged with usb a to c. 5V)
Plugging in USB : No LED, COM port identified as COM3, unable to upload firmware.
(Cannot identify esp8266 - Timed out)

[In detail - Wemos detached from board]
Plugging in USB : Blue LED, COM port identified as COM3, able to upload firmware.

I'm assuming that the soldering order is the problem. (I've been soldering components in random order)
Is there any specific order to soldering to avoid board malfunctioning?

(Sorry, am I in right place to ask question?)

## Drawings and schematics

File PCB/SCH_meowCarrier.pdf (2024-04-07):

## INT1

## SCL

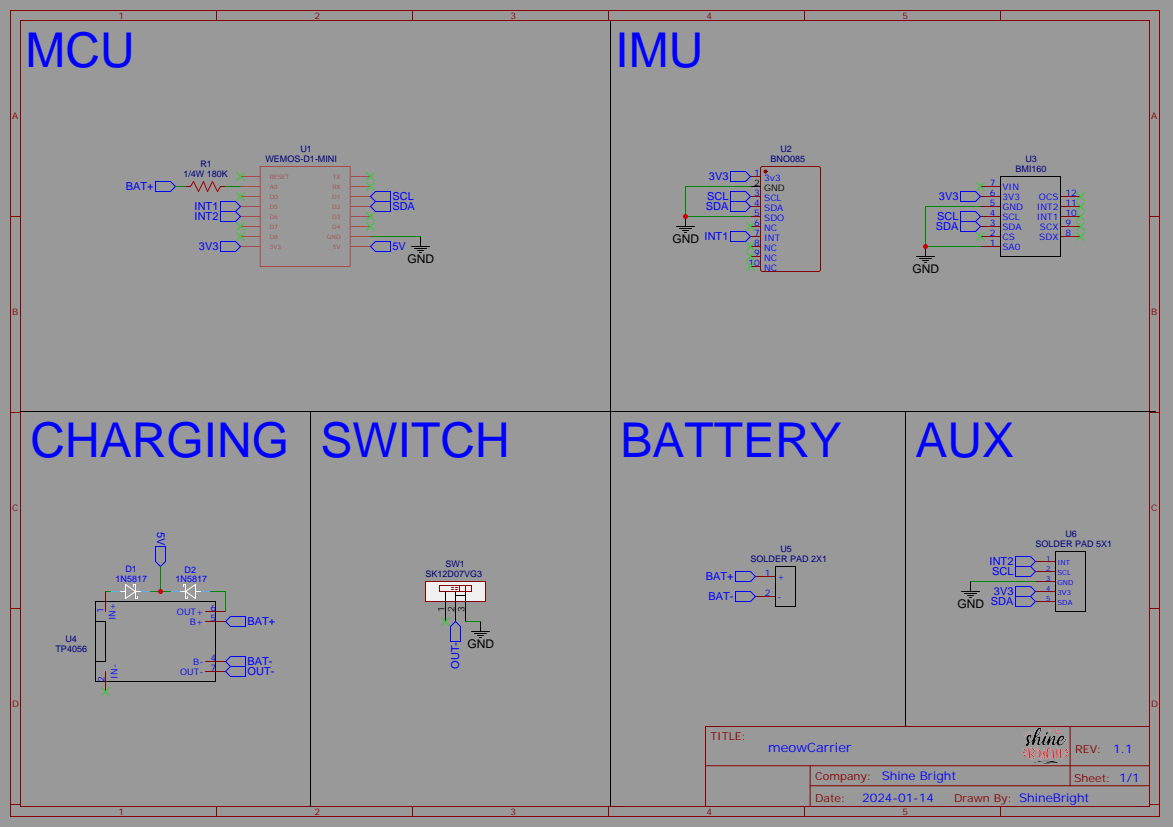
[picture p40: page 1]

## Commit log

2024-04-07 Update and rename PCB.txt to README.md
2024-04-07 Update and rename Printables.txt to README.md
2024-04-07 Update and rename STL.txt to README.md
2024-04-17 More Optimization (Smaller and Less Material!)
    [CASE_meowCarrier_503759_GoPro.stl, CASE_meowCarrier_503759_GoPro2.stl, CASE_meowCarrier_503759_GoPro2_AUX.stl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]
2024-04-19 STEP Files
    [CASE_meowCarrier_503759_GoPro.step, CASE_meowCarrier_503759_GoPro2.step, CASE_meowCarrier_503759_GoPro2_AUX.step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]
2024-04-19 PCB Source File
2024-04-20 PCB with PH Battery Connector
2024-04-26 Optimization and Reduced Tolerances
    [CASE_meowCarrier_503759_GoPro.stl, CASE_meowCarrier_503759_GoPro2.stl, CASE_meowCarrier_503759_GoPro2_AUX.stl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]
2024-05-01 Reword PCB Thickness Recommendation
2024-05-18 Moved PH Connector back a bit more
2024-05-27 Fixed GoPro Adapter Separation
    [CASE_meowCarrier_503759_GoPro.step, CASE_meowCarrier_503759_GoPro.stl, CASE_meowCarrier_503759_GoPro_AUX.step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]
2024-05-27 Reapplied fillet to GoPro Adapter
    [CASE_meowCarrier_503759_GoPro.step, CASE_meowCarrier_503759_GoPro.stl, CASE_meowCarrier_503759_GoPro_AUX.step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]
2024-06-15 Clarify soldering for Slime BNO
2024-06-29 Rotated Lids 180 degrees for printing
    [LID_meowCarrier_503759.stl, LID_meowCarrier_AUX.stl]
2025-09-05 docs: IMU Update
